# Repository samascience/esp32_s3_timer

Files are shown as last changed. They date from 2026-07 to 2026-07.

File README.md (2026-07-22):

# ESP32-C3 0.42" OLED Schedule Timer & Web Portal

<p align="center">
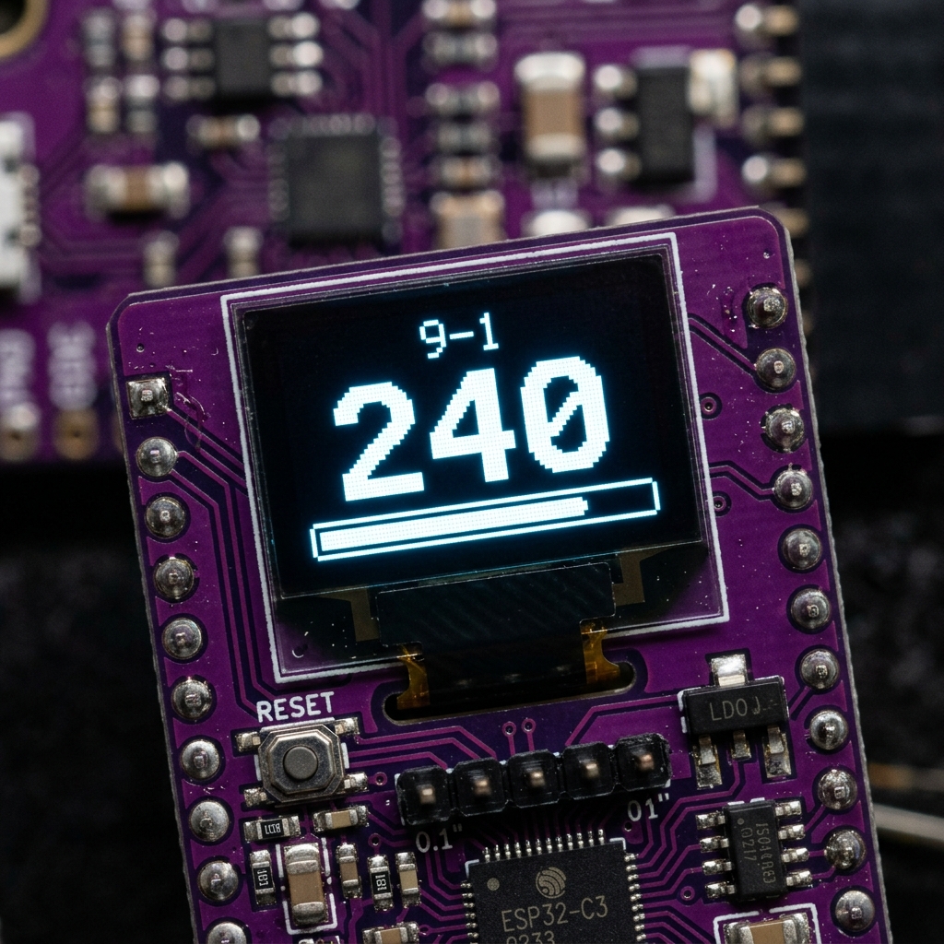
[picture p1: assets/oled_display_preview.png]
OLED Display Preview
  
  &nbsp;&nbsp;
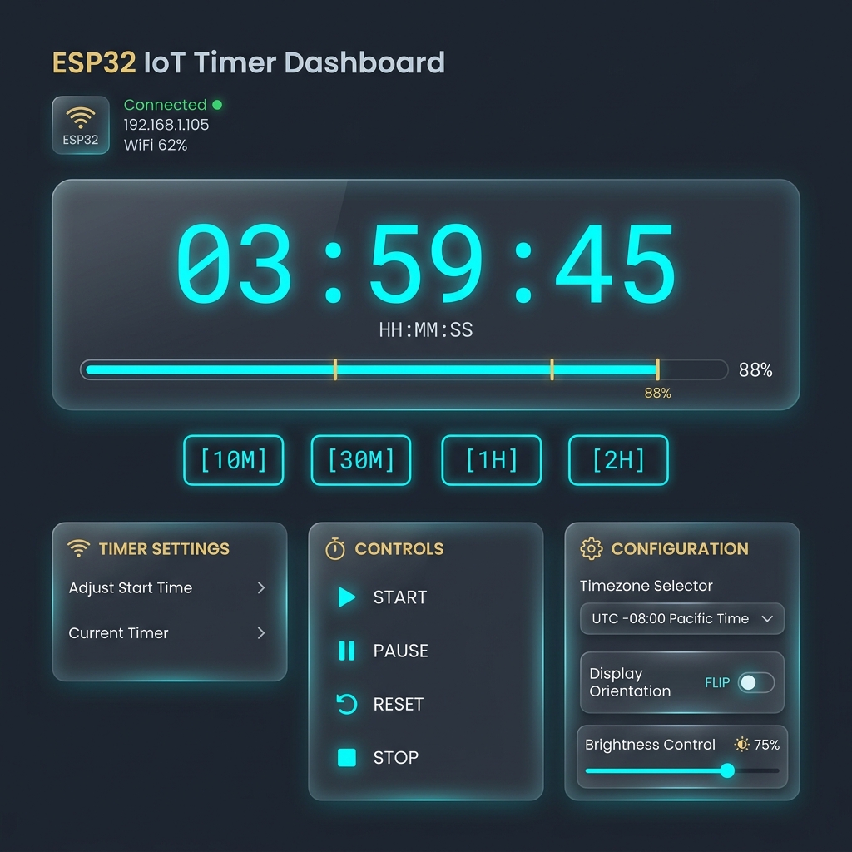
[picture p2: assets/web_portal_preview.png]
Web Portal Preview
  
</p>

A feature-packed MicroPython project for the **ESP32-C3 Supermini Development Board** featuring an onboard **0.42-inch OLED display (SH1106 controller)**. It maintains real-time NTP synchronization, executes a **5-block customizable daily countdown schedule**, renders dynamically scaled numbers to maximize screen space, and hosts an asynchronous **dark-mode web dashboard** for real-time control and customizations.

---

## 🌟 Key Features

* **0.42" OLED Integration:** Customized driver for the SH1106 controller with physical viewport mapping (`x_offset = 28`, `y_offset = 12`).
* **High-Density Display Rendering:** Dynamically scales font size (up to 3x height) to display remaining minutes clearly across the room.
* **5 Daily Schedule Blocks:** Configurable daily intervals (e.g., `12-9`, `9-1`, `1-5`, `5-9`, `9-12`).
* **NTP Synchronization:** Automatic background time sync via Wi-Fi with persistent UTC timezone offset settings.
* **Interactive Web Dashboard:** Glassmorphic UI to monitor status, set custom overrides, adjust brightness, flip display 180°, and change block schedule times.
* **1-Click 180° Screen Flip:** Hardware display orientation toggle available via web UI or API.
* **Sanitized Credentials:** Configuration stored in `config.json` (with `config.json.example` template provided for open-source sharing).

---

## 📐 Hardware Connections & Specification

| Hardware Component | ESP32-C3 Pin | Notes |
| :--- | :--- | :--- |
| **OLED SDA** | `GPIO 5` | I2C Data Line |
| **OLED SCL** | `GPIO 6` | I2C Clock Line |
| **Display Chip** | SH1106 | 128x64 internal buffer, 72x40 physical window |
| **Power Input** | USB-C (5V) | Onboard 3.3V LDO regulator |

---

## 📁 Repository Structure

```text
.
├── main.py              # Core application logic, display loop, scheduler, and web server
├── sh1106.py            # MicroPython driver for SH1106 I2C OLED display
├── index.html           # Embedded dark-mode web portal dashboard
├── config.json.example  # Configuration template (rename to config.json)
├── case.scad            # Parametric OpenSCAD 3D model for laptop-style enclosure
├── stl/                 # 3D Printable STL Files
│   └── case_stand.stl   # Single-piece support-free angled desktop stand
└── README.md            # Project documentation and setup guide
```

---

## 🖨️ 3D Printable Desktop Stand (100% Support-Free)

A custom parametric **OpenSCAD model (`case.scad`)** is included so you can 3D print a desktop stand for your ESP32-C3 timer in under 15 minutes!

* **100% Support-Free Printing:** Designed with draft angles under 45° so it prints directly flat on any 3D printer without any support material.
* **Ergonomic 60° Viewing Angle:** Elevates and slants the screen towards your eyes for desk viewing.
* **Fast & Light:** Prints in ~15 minutes using ~8 grams of filament.
* **Plug & Play:** Slide the ESP32-C3 board right into the front slot; rear cutout allows easy USB-C cable access and bottom hole enables quick removal.

### Slicing & Printing

The pre-compiled STL file is located in the `stl/` directory:
* `stl/case_stand.stl`: Print flat on the print bed (Layer height: 0.2mm, Infill: 15–20%, **Supports: Disabled**).

To re-compile from command line:

```bash
openscad -o stl/case_stand.stl -D 'render_part="stand"' case.scad
```

---

## 🚀 Step-by-Step Setup & Installation Guide

### Prerequisites

Install the required Python tools on your host machine:

```bash
pip install esptool mpremote
```

---

### Step 1: Flash MicroPython Firmware

1. Connect your ESP32-C3 Supermini to your computer via USB-C.
2. Identify your serial port device:
   * **macOS:** `/dev/cu.usbmodem*`
   * **Linux:** `/dev/ttyUSB*` or `/dev/ttyACM*`
   * **Windows:** `COM3` (or similar)

3. Erase the ESP32-C3 flash memory:

   ```bash
   esptool.py --chip esp32c3 --port /dev/cu.usbmodem14101 erase_flash
   ```

4. Download the latest stable MicroPython firmware for **ESP32_GENERIC_C3** from [MicroPython.org](https://micropython.org/download/ESP32_GENERIC_C3/).

5. Write the MicroPython firmware to the board at offset `0x0`:

   ```bash
   esptool.py --chip esp32c3 --port /dev/cu.usbmodem14101 --baud 460800 write_flash 0x0 ESP32_GENERIC_C3-20260406-v1.28.0.bin
   ```

---

### Step 2: Configure Settings

1. Copy the example configuration file:

   ```bash
   cp config.json.example config.json
   ```

2. Open `config.json` and fill in your Wi-Fi credentials and preferences:

   ```json
   {
     "wifi_ssid": "YOUR_WIFI_NAME",
     "wifi_pass": "YOUR_WIFI_PASSWORD",
     "tz_offset": -5,
     "flip_display": false,
     "brightness": 255,
     "t1": 9,
     "t2": 13,
     "t3": 17,
     "t4": 21
   }
   ```

---

### Step 3: Upload Project Files to ESP32

Use `mpremote` to copy all required files to the root of the ESP32 filesystem:

```bash
mpremote connect /dev/cu.usbmodem14101 fs cp sh1106.py :sh1106.py
mpremote connect /dev/cu.usbmodem14101 fs cp index.html :index.html
mpremote connect /dev/cu.usbmodem14101 fs cp config.json :config.json
mpremote connect /dev/cu.usbmodem14101 fs cp main.py :main.py
```

---

### Step 4: Boot the Device

Reset the ESP32 to start the application:

```bash
mpremote connect /dev/cu.usbmodem14101 reset
```

---

## 🌐 Web Portal & API Reference

Once booted, the ESP32 will connect to Wi-Fi, obtain an IP address via DHCP (e.g. `192.168.1.103`), and host the web dashboard on port 80.

Access the dashboard by navigating to:
**`http://<ESP32-IP>/`** or **`http://<ESP32-IP>/index.html`**

### Available API Endpoints

| Endpoint | Method | Description |
| :--- | :--- | :--- |
| `/` or `/index.html` | `GET` | Returns the web dashboard |
| `/api/status` | `GET` | Returns JSON status (current time, remaining minutes, progress, settings) |
| `/api/set?mins=X` | `POST` | Starts a custom countdown timer for `X` minutes |
| `/api/reset` | `POST` | Clears custom timer and reverts to the default schedule |
| `/api/rotate` | `POST` | Toggles display orientation 180° |
| `/api/set_config?...` | `POST` | Updates timezone, brightness, rotation, and schedule hours |

---

## ⚙️ Customization Parameters

| Parameter | Type | Default | Description |
| :--- | :--- | :--- | :--- |
| `tz_offset` | `int` | `-5` | UTC timezone offset in hours |
| `brightness` | `int` | `255` | OLED contrast value (31=Low, 127=Med, 255=High) |
| `flip_display` | `bool` | `false` | Flips screen orientation 180° |
| `t1` | `int` | `9` | Start hour for Block 2 (e.g., 9 = 9 AM) |
| `t2` | `int` | `13` | Start hour for Block 3 (e.g., 13 = 1 PM) |
| `t3` | `int` | `17` | Start hour for Block 4 (e.g., 17 = 5 PM) |
| `t4` | `int` | `21` | Start hour for Block 5 (e.g., 21 = 9 PM) |

---

## 📄 License

This project is open-source and available under the [MIT License](LICENSE).

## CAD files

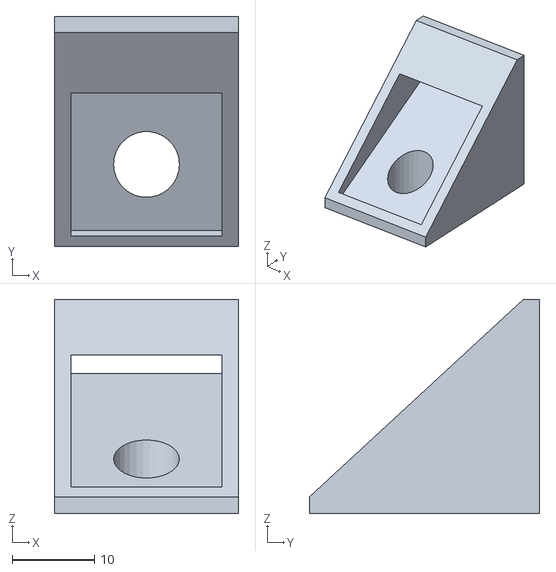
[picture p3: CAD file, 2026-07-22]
stl/case_stand.stl
22.4 x 28.0 x 26.0

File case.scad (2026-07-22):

// ====================================================================
// ESP32-C3 0.42" OLED Ultra-Simple Support-Free Desktop Stand
// Designed for 100% Support-Free Printing & Fast 15-Min Print Time
// ====================================================================

/* [Render Selection] */
// Select part to render: "stand" (Single-piece stand), "bezel" (Front cover)
render_part = "stand";

/* [Dimensions] */
pcb_w = 18.4;       // ESP32 PCB width (mm) + clearance
pcb_l = 24.0;      // ESP32 PCB length (mm) + clearance
pcb_t = 1.6;       // PCB thickness (mm)
wall  = 2.0;       // Wall thickness (mm)
slant = 60;        // Display viewing angle (degrees)

// Viewport cutout dimensions for 0.42" OLED
view_w = 15.0;
view_h = 9.0;

$fn = 30; // Smoothness

// ====================================================================
// 1-PIECE SUPPORT-FREE SLANTED DESKTOP STAND
// ====================================================================
module simple_stand() {
    outer_w = pcb_w + (wall * 2);
    outer_d = 28.0;
    height  = 26.0;
    
    difference() {
        // Main Wedge Body (Flat bottom, angled front face)
        hull() {
            // Flat Bottom Base
            cube([outer_w, outer_d, 2]);
            
            // Top Rear Ridge
            translate([0, outer_d - wall, height - wall])
                cube([outer_w, wall, wall]);
        }
        
        // Slanted Front Pocket for ESP32 + Screen
        translate([wall, wall, wall])
            rotate([90 - slant, 0, 0])
                cube([pcb_w, 40, pcb_t + 5]);
                
        // Screen Viewport Window Cutout (Front)
        translate([(outer_w - view_w)/2, 0, 10])
            rotate([90 - slant, 0, 0])
                translate([0, 0, -5])
                    cube([view_w, view_h, 15]);
                    
        // Rear USB-C Cable Access Port
        translate([(outer_w - 10)/2, outer_d - 5, -1])
            cube([10, 10, 8]);
            
        // Finger Push Hole at bottom to easily remove board
        translate([outer_w/2, 10, -1])
            cylinder(r=4, h=10);
    }
}

// ====================================================================
// FRONT CLIP BEZEL (OPTIONAL SNAP FRAME)
// ====================================================================
module front_bezel() {
    outer_w = pcb_w + (wall * 2);
    height = 20.0;
    
    difference() {
        cube([outer_w, height, 1.6]);
        
        // Center Viewport Cutout
        translate([(outer_w - view_w)/2, (height - view_h)/2, -1])
            cube([view_w, view_h, 4]);
    }
}

// ====================================================================
// RENDER SELECTION
// ====================================================================
if (render_part == "stand") {
    simple_stand();
} else if (render_part == "bezel") {
    front_bezel();
}

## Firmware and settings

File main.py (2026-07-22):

import machine
from machine import Pin, SoftI2C, RTC
import time
import json
import network
import ntptime
import asyncio
import sh1106
import sys
import framebuf

# Global Variables / Config Defaults
config = {
    "wifi_ssid": "Antharjalam",
    "wifi_pass": "Superman$9",
    "tz_offset": -5,
    "flip_display": False,
    "brightness": 255,
    "t1": 9,   # Block 2 start (9 AM)
    "t2": 13,  # Block 3 start (1 PM)
    "t3": 17,  # Block 4 start (5 PM)
    "t4": 21   # Block 5 start (9 PM)
}

custom_timer_end = None
custom_timer_duration = 0
ntp_synced = False

# Read persistent configuration
def load_config():
    global config
    try:
        with open('config.json', 'r') as f:
            cfg = json.load(f)
            config.update(cfg)
            print("Loaded config successfully.")
    except Exception as e:
        print("Using default config, error:", e)

def save_config():
    try:
        with open('config.json', 'w') as f:
            json.dump(config, f)
        print("Saved config successfully.")
    except Exception as e:
        print("Failed to save config:", e)

load_config()

# Display Setup
# Standard 0.42" OLED is SH1106 128x64 with offsets (28, 12)
oled = None

def apply_display_config():
    if oled is None:
        return
    try:
        # Set Contrast / Brightness
        oled.write_cmd(0x81)
        oled.write_cmd(config["brightness"])
        
        # Set internal IREF
        oled.write_cmd(0xAD)
        oled.write_cmd(0x30)
        
        # Set flip orientation
        oled.flip(config["flip_display"])
    except Exception as e:
        print("Error applying display config:", e)

try:
    i2c = SoftI2C(sda=Pin(5), scl=Pin(6), freq=400000)
    oled = sh1106.SH1106_I2C(128, 64, i2c)
    apply_display_config()
    print("OLED display (SH1106) initialized successfully.")
except Exception as e:
    print("OLED display initialization failed:", e)

# Helper to draw large (scaled) text using a temporary FrameBuffer
def draw_large_text(text, x, y, scale=2):
    if oled is None:
        return
    
    w = len(text) * 8
    h = 8
    buf_size = (w * h) // 8 + 1
    buf = bytearray(buf_size)
    tb = framebuf.FrameBuffer(buf, w, h, framebuf.MONO_VLSB)
    tb.fill(0)
    tb.text(text, 0, 0, 1)
    
    for ty in range(h):
        for tx in range(w):
            if tb.pixel(tx, ty):
                oled.fill_rect(x + tx * scale, y + ty * scale, scale, scale, 1)

def update_oled():
    if oled is None:
        return
    
    try:
        oled.fill(0)
        
        # Get current state
        mode, current_time_str, remaining_secs, active_range, progress = get_system_status()
        
        # Coordinates offset
        x_off = 28
        y_off = 12
        
        rem_mins = (remaining_secs + 59) // 60
        min_text = str(rem_mins)
        scale = 3 if len(min_text) <= 3 else 2
        large_w = len(min_text) * 8 * scale
        large_x = x_off + (72 - large_w) // 2
        
        if mode != "custom":
            # 1. Draw Range Tab (centered at the top)
            text_w = len(active_range) * 8
            range_x = x_off + (72 - text_w) // 2
            oled.text(active_range, range_x, y_off + 0, 1)
            
            # 2. Draw Minutes Only
            draw_large_text(min_text, large_x, y_off + 10, scale)
        else:
            # Custom mode: No top range tab, vertically centered large minutes
            y_pos = y_off + (6 if scale == 3 else 8)
            draw_large_text(min_text, large_x, y_pos, scale)
        
        # 3. Draw Progress Bar (at the bottom, y = y_off + 35)
        oled.rect(x_off + 2, y_off + 35, 68, 5, 1)
        if progress > 0:
            fill_w = int(64 * min(max(progress, 0.0), 1.0))
            if fill_w > 0:
                oled.fill_rect(x_off + 4, y_off + 37, fill_w, 1, 1)
                
        oled.show()
    except Exception as e:
        print("OLED drawing error:", e)

# Wi-Fi setup (Station mode to connect to router)
ssid = config.get("wifi_ssid", "YOUR_WIFI_SSID")
password = config.get("wifi_pass", "YOUR_WIFI_PASSWORD")

wlan = network.WLAN(network.STA_IF)
wlan.active(False)
time.sleep(1.0)
wlan.active(True)
time.sleep(0.5)
print("Connecting to Wi-Fi...")
wlan.connect(ssid, password)

# Network background task
async def wifi_monitor_task():
    await asyncio.sleep(15)
    while True:
        if not wlan.isconnected() and wlan.status() != network.STAT_CONNECTING:
            s = config.get("wifi_ssid", "YOUR_WIFI_SSID")
            p = config.get("wifi_pass", "YOUR_WIFI_PASSWORD")
            try:
                wlan.connect(s, p)
            except Exception as e:
                pass
        await asyncio.sleep(10)

# NTP Sync Task
async def ntp_sync_task():
    global ntp_synced
    while True:
        if wlan.isconnected():
            try:
                print("Syncing time with NTP...")
                ntptime.settime()
                ntp_synced = True
                print("NTP time sync successful. Current UTC time:", time.localtime())
                await asyncio.sleep(12 * 3600)
            except Exception as e:
                print("NTP sync failed, retrying in 15s. Error:", e)
                await asyncio.sleep(15)
        else:
            await asyncio.sleep(5)

# Timer logic helper functions
def get_local_seconds():
    return time.time() + int(config["tz_offset"] * 3600)

def fmt_hr(h):
    h_12 = h % 12
    return 12 if h_12 == 0 else h_12

def get_system_status():
    global custom_timer_end, custom_timer_duration
    
    local_secs = get_local_seconds()
    local_tuple = time.localtime(local_secs)
    hour = local_tuple[3]
    minute = local_tuple[4]
    second = local_tuple[5]
    
    current_time_str = "{:02d}:{:02d}:{:02d}".format(hour, minute, second)
    
    # Check if custom timer is active
    if custom_timer_end is not None:
        utc_now = time.time()
        if utc_now < custom_timer_end:
            remaining_secs = int(custom_timer_end - utc_now)
            progress = 0.0
            if custom_timer_duration > 0:
                progress = (custom_timer_duration - remaining_secs) / custom_timer_duration
            return "custom", current_time_str, remaining_secs, "Custom", progress
        else:
            custom_timer_end = None
            custom_timer_duration = 0
            
    current_mins = hour * 60 + minute
    
    # Get config transition hours (5 blocks, 4 transition points)
    t1_mins = config.get("t1", 9) * 60
    t2_mins = config.get("t2", 13) * 60
    t3_mins = config.get("t3", 17) * 60
    t4_mins = config.get("t4", 21) * 60
    
    r1 = "12-{}".format(fmt_hr(config.get("t1", 9)))
    r2 = "{}-{}".format(fmt_hr(config.get("t1", 9)), fmt_hr(config.get("t2", 13)))
    r3 = "{}-{}".format(fmt_hr(config.get("t2", 13)), fmt_hr(config.get("t3", 17)))
    r4 = "{}-{}".format(fmt_hr(config.get("t3", 17)), fmt_hr(config.get("t4", 21)))
    r5 = "{}-12".format(fmt_hr(config.get("t4", 21)))
    
    if t1_mins <= current_mins < t2_mins:
        active_range = r2
        total_duration_secs = (t2_mins - t1_mins) * 60
        remaining_secs = (t2_mins * 60) - (current_mins * 60 + second)
    elif t2_mins <= current_mins < t3_mins:
        active_range = r3
        total_duration_secs = (t3_mins - t2_mins) * 60
        remaining_secs = (t3_mins * 60) - (current_mins * 60 + second)
    elif t3_mins <= current_mins < t4_mins:
        active_range = r4
        total_duration_secs = (t4_mins - t3_mins) * 60
        remaining_secs = (t4_mins * 60) - (current_mins * 60 + second)
    elif t4_mins <= current_mins < 1440:
        active_range = r5
        total_duration_secs = (1440 - t4_mins) * 60
        remaining_secs = (1440 * 60) - (current_mins * 60 + second)
    else: # 0 to t1_mins
        active_range = r1
        total_duration_secs = t1_mins * 60
        remaining_secs = (t1_mins * 60) - (current_mins * 60 + second)
            
    if remaining_secs < 0:
        remaining_secs = 0
        
    progress = (total_duration_secs - remaining_secs) / total_duration_secs if total_duration_secs > 0 else 0.0
    return "default", current_time_str, remaining_secs, active_range, progress

# Web request handlers
async def handle_client(reader, writer):
    global custom_timer_end, custom_timer_duration
    
    try:
        request_line = await reader.readline()
        if not request_line:
            return
            
        req = request_line.decode('utf-8').split()
        if len(req) < 2:
            return
            
        method, path = req[0], req[1]
        
        # Read remaining headers
        while True:
            line = await reader.readline()
            if line == b'\r\n' or line == b'\n':
                break
                
        if method == 'GET' and path in ('/', '/index.html'):
            # Serve index.html
            writer.write(b"HTTP/1.1 200 OK\r\nContent-Type: text/html\r\nConnection: close\r\n\r\n")
            try:
                with open('index.html', 'rb') as f:
                    while True:
                        chunk = f.read(256)
                        if not chunk:
                            break
                        writer.write(chunk)
                        await writer.drain()
            except Exception as e:
                writer.write(b"Error reading index.html")
                
        elif method == 'GET' and path == '/api/status':
            # Serve JSON status
            mode, current_time_str, remaining_secs, active_range, progress = get_system_status()
            status_json = {
                "mode": mode,
                "current_time": current_time_str,
                "remaining_secs": remaining_secs,
                "active_range": active_range,
                "progress": progress,
                "tz_offset": config["tz_offset"],
                "brightness": config["brightness"],
                "flip_display": config["flip_display"],
                "t1": config.get("t1", 9),
                "t2": config.get("t2", 13),
                "t3": config.get("t3", 17),
                "t4": config.get("t4", 21)
            }
            res_body = json.dumps(status_json)
            writer.write(b"HTTP/1.1 200 OK\r\nContent-Type: application/json\r\nConnection: close\r\n\r\n")
            writer.write(res_body.encode('utf-8'))
            
        elif method == 'POST' and path.startswith('/api/set'):
            mins = 0
            if 'mins=' in path:
                try:
                    mins = int(path.split('mins=')[1].split('&')[0])
                except:
                    pass
            if mins > 0:
                custom_timer_duration = mins * 60
                custom_timer_end = time.time() + custom_timer_duration
                print("Started custom timer for {} minutes".format(mins))
                
            writer.write(b"HTTP/1.1 200 OK\r\nContent-Type: application/json\r\nConnection: close\r\n\r\n")
            writer.write(b'{"status":"ok"}')
            
        elif method == 'POST' and path == '/api/reset':
            custom_timer_end = None
            custom_timer_duration = 0
            print("Reset to default schedule timer")
            writer.write(b"HTTP/1.1 200 OK\r\nContent-Type: application/json\r\nConnection: close\r\n\r\n")
            writer.write(b'{"status":"ok"}')
            
        elif method == 'POST' and path.startswith('/api/set_config'):
            params = {}
            if '?' in path:
                q = path.split('?')[1]
                for pair in q.split('&'):
                    if '=' in pair:
                        k, v = pair.split('=')
                        params[k] = v
            
            # Update configuration
            if 'tz_offset' in params:
                config['tz_offset'] = int(params['tz_offset'])
            if 'flip_display' in params:
                config['flip_display'] = params['flip_display'] in ('1', 'true', 'True')
            if 'brightness' in params:
                config['brightness'] = int(params['brightness'])
            if 't1' in params: config['t1'] = int(params['t1'])
            if 't2' in params: config['t2'] = int(params['t2'])
            if 't3' in params: config['t3'] = int(params['t3'])
            if 't4' in params: config['t4'] = int(params['t4'])
                
            apply_display_config()
            save_config()
            
            writer.write(b"HTTP/1.1 200 OK\r\nContent-Type: application/json\r\nConnection: close\r\n\r\n")
            writer.write(b'{"status":"ok"}')
            
        elif method == 'POST' and path == '/api/rotate':
            config['flip_display'] = not config.get('flip_display', False)
            apply_display_config()
            save_config()
            
            res_val = b"true" if config['flip_display'] else b"false"
            writer.write(b"HTTP/1.1 200 OK\r\nContent-Type: application/json\r\nConnection: close\r\n\r\n")
            writer.write(b'{"status":"ok","flip_display":' + res_val + b'}')
            
        else:
            writer.write(b"HTTP/1.1 404 Not Found\r\nContent-Type: text/plain\r\nConnection: close\r\n\r\n")
            writer.write(b"Not Found")
            
        await writer.drain()
    except Exception as e:
        print("Web handling error:", e)
    finally:
        await writer.aclose()

# Timer and Display Update Task
async def display_timer_task():
    while True:
        update_oled()
        await asyncio.sleep(1)

# Main async runner
async def main():
    # Start web server
    print("Starting web server on port 80...")
    server = await asyncio.start_server(handle_client, "0.0.0.0", 80)
    
    # Start background tasks
    asyncio.create_task(wifi_monitor_task())
    asyncio.create_task(ntp_sync_task())
    asyncio.create_task(display_timer_task())
    
    print("System running. Waiting for connections...")
    while True:
        await asyncio.sleep(3600)

try:
    asyncio.run(main())
except KeyboardInterrupt:
    print("Shutting down...")

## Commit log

2026-07-22 Initial commit: ESP32-C3 OLED Schedule Timer & Web Portal
2026-07-22 Add parametric OpenSCAD 3D laptop case model and STL files
    [case.scad, case_base.stl, case_hinge.stl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]
2026-07-22 Update OpenSCAD model to use integrated snap-fit hinge and mechanical tilt stop
    [case.scad, case_base.stl, case_hinge.stl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]
2026-07-22 Simplify 3D print model to a 100% support-free 1-piece slanted desktop stand
    [case.scad, case_base.stl, case_lid.stl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]
